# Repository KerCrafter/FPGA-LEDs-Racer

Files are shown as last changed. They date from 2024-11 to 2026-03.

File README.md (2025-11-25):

# LEDs Racer

## Description

A fun little game, 4 players (Red, Blue, Green, Yellow) around a table, each with an arcade button, must challenge each other by pressing their button as fast as possible.

Pressing the button causes their led to progress to the center circle. The first to reach the center wins.

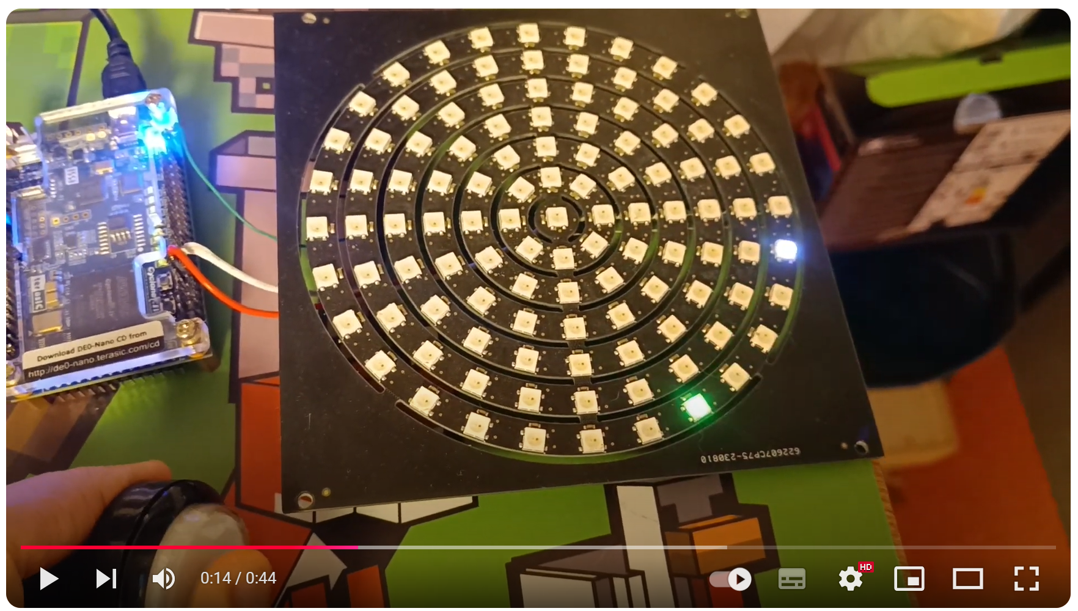
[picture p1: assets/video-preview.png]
Video Preview (https://youtu.be/GDuj1pzoBWQ)


## Platforms

### FPGAs

- DE0 Nano

### Tiny Tapeout Chips 

| Chip Name | Build | Status |
|--|--|--|
| [**TTSKY25b**](https://tinytapeout.com/chips/ttsky25b/tt_um_kercrafter_leds_racer) |    | Submitted (production in progress) |
| [**TTGFp02**](https://app.tinytapeout.com/projects/3455) |    | Submitted (production in progress) |
| **TTIHP26a** | Upcoming project | Not Submitted |

## Hardware

I'm putting here the material I used for the project, but of course if it's compatible this list can be adapted.

- 4 x **Arcade buttons** (https://www.amazon.fr/EG-STARTS-Nouveau-Boutons-poussoirs-lumineux/dp/B01MSNXLN0/)
- 1 x **LEDs Circles (with WS2812B Leds)** (https://www.amazon.fr/Treedix-anneaux-WS2812B-adressable-Raspberry/dp/B0CD3DYJRK/)
- 1 x **FPGA DE0 Nano** (https://www.mouser.fr/ProductDetail/Terasic-Technologies/P0082?qs=ePbE9GiMmvUo6nLfdjJv4g%3D%3D)

## Software IDE

I'm putting here the software I use for development to date. It's possible that these technical considerations may change depending on the target material.

- Quartus Prime Lite
- Questa Sim

## Install

Go to this [install guide](./docs/install.md)

## Run Unit Test Benches (With VUnit)

Require **Docker Client** installed and just run :

`./run_tests.sh`

## Actual State
**549** Logic Element (LE) - **232** Registers

I concentrated mainly on implementing the WS2812B LED driver. With the help of the testbench tool, I implemented tests as I went along in order to discover the communication algorithm with the WS2812B LED serial line.

the project works correctly End to End with DE0 Nano device.

### Todo options

- Music
- Random traps
- [Electronic Experimentation] Reduce number of CLK edges required to debounce button, it could be interesting to test with a capacitor.

### Identified problems

- From Test Bench we identify a problem about the RED Player led seems move two positions direcly : it's described in [LEDs_racer_main_tb](./LEDs_racer_main_tb.vhd#L414) / [this doc](./docs/sim_counter_problem.md)

## Architecture (Top View Usage)

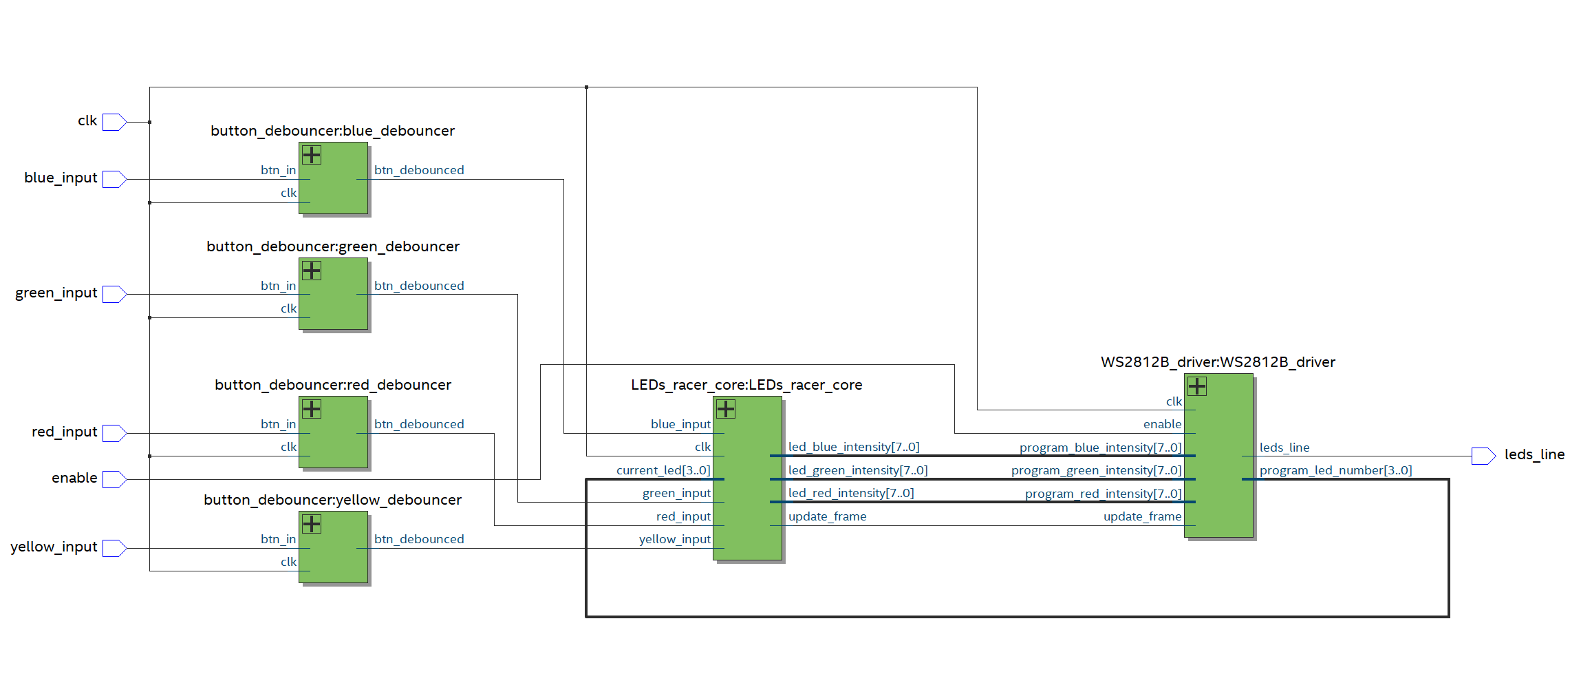
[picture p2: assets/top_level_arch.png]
Top View Architecture


|  pin input | input description  | output description |  pin output |
|  :--- |  :--- | ---: |  ---: |
|  **clk**  |  50 Mhz clock input signal  |  WS2812B transmission  |  **leds_line**  |
|  **red_input**  |  Player Red input (connected to Red button) or Grounded  | |  |
|  **green_input**  |  Player Green input (connected to Green button) or Grounded  | |  |
|  **blue_input**  |  Player Blue input (connected to Blue button) or Grounded  | |  |
|  **yellow_input**  |  Player Yellow input (connected to Yellow button) or Grounded  | |  |

### LEDs Racer Core Architecture

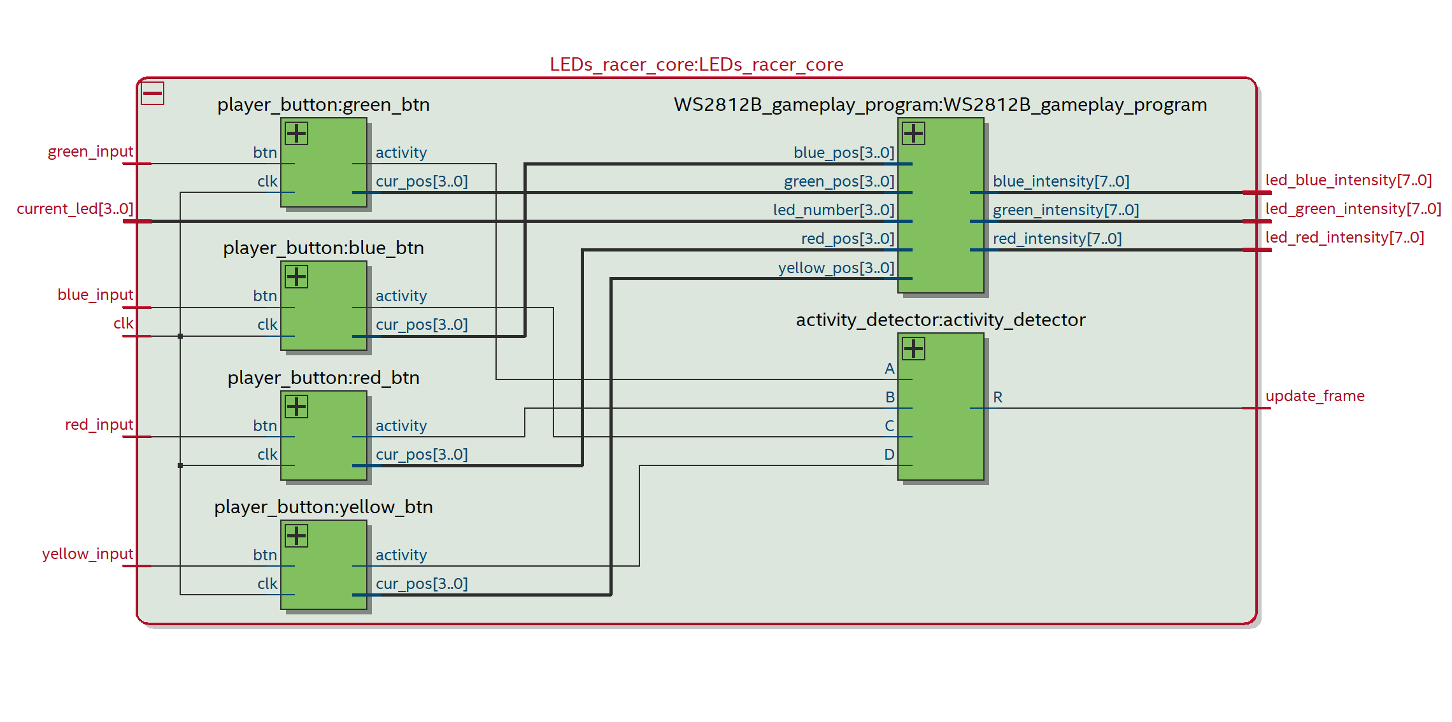
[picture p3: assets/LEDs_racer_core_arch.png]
LEDs Racer Core Architecture


### See more about sub-components

- [Button Debouncer](https://github.com/KerCrafter/button-debouncer)
- [Player Button](./docs/player_button.md)
- [Activity Detector](./docs/activity_detector.md)
- [WS2812B Driver](https://github.com/KerCrafter/WS2812B-driver)
- [WS2812B Gameplay Program](./docs/ws2812b_gameplay_program.md)

## Schematic

### Buttons

Should be connected to the FPGA inputs with a pull down resistor (note: not sure 1M is an ideal value)

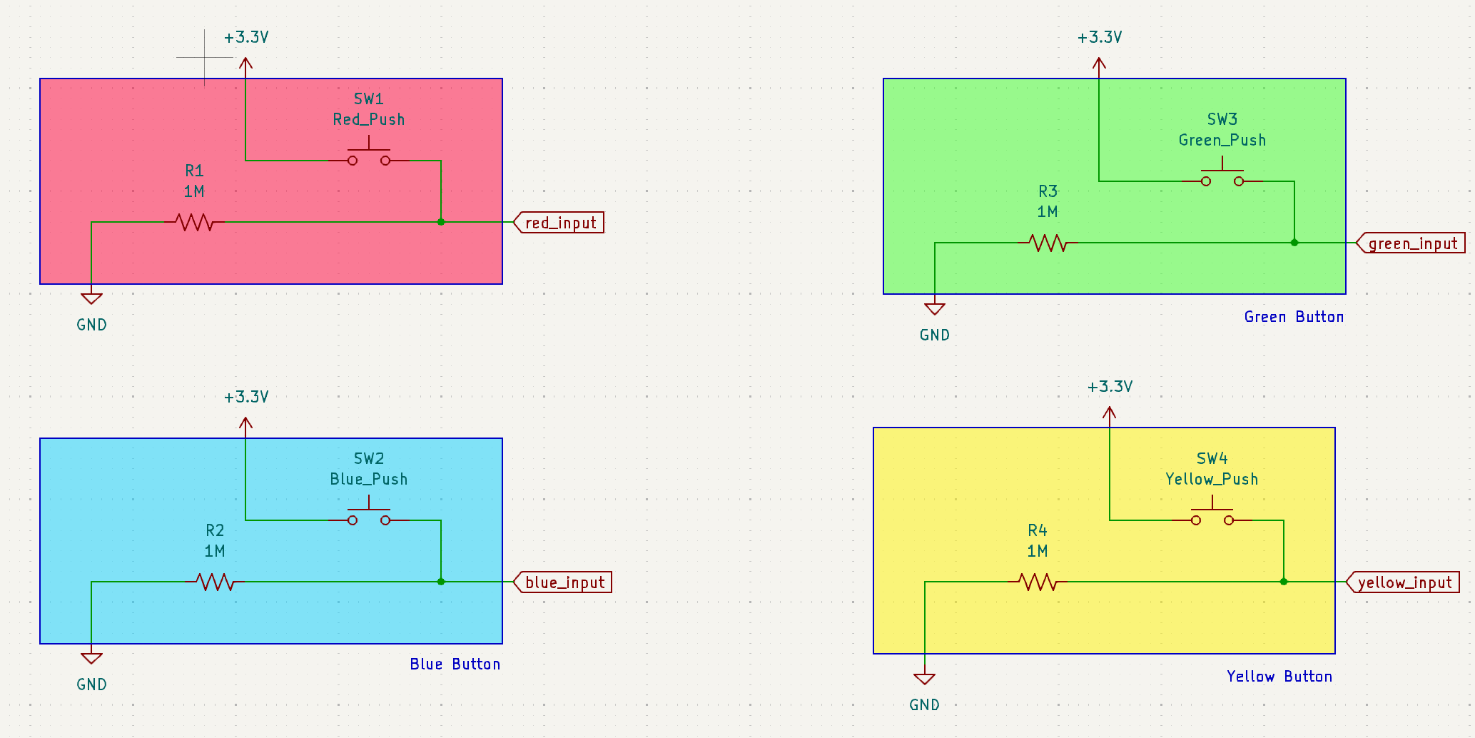
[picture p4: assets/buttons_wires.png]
Buttons Wires

[race_4_players.kicad_sch](./schematic/race_4_players/race_4_players.kicad_sch)

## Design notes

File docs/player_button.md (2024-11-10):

# Player Button

Manage the input for ONE player, typically Yellow player implement one instance of this

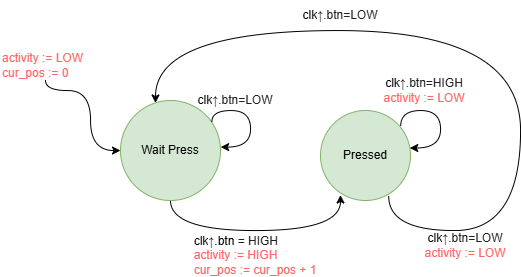
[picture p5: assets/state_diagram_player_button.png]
State Diagram of Player Button


## Responsabilities :

- Increments a counter at each press into the button
- Send a short impulsion just to inform that the displayed informations has changed

## RTL Architecture

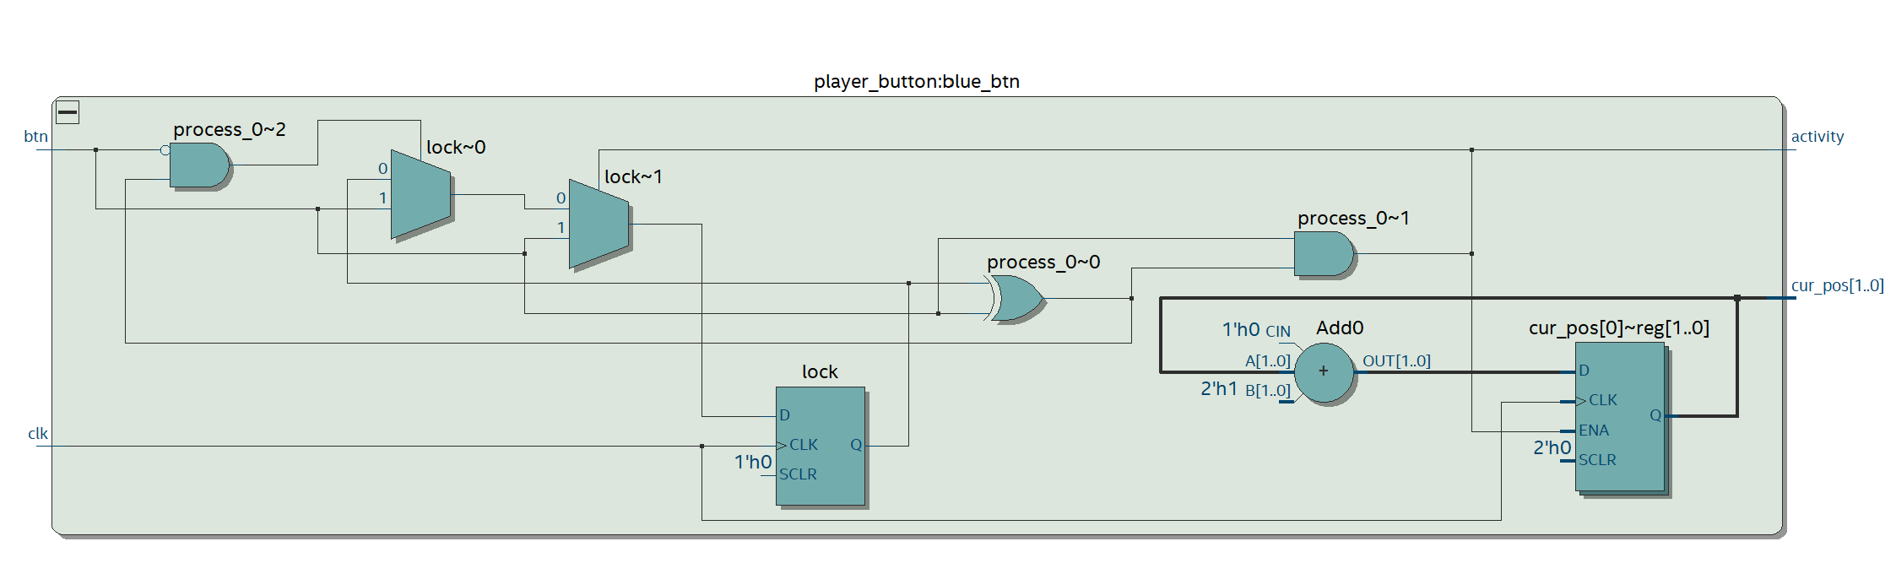
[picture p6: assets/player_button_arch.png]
Player Button Architecture


|  pin input | input description  | output description |  pin output |
|  :--- |  :--- | ---: |  ---: |
|  **clk**  |  50 Mhz clock input signal  |  Up to HIGH during one clk cycle when button is pressed  |  **activity**  |
|  **btn**  |  Connected to the button  | Actual position of the player | **cur_pos[1..0]** |

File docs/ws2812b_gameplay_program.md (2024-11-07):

# WS2812B Gameplay Program

Displaying logic per LEDs. designed to work with WS2812B Driver.

## Responsabilities :

- Receive players positions 
- Reveive position of current LED should be coded
- Send Green/Red/Blue light intensity for the WS2812B driver

## Displaying Rules

- White (Green: 5, Red: 5, Blue: 5) when 2+ players are in the LED.
- Black (OR light off => Green: 0, Red: 0, Blue: 0) when no players are actually in the LED.
- Green (Green 10, Red: 0, Blue: 0) when only Green player is in the LED.
- Red (Green 0, Red: 10, Blue: 0) when only Red player is in the LED.
- Blue (Green 0, Red: 0, Blue: 10) when only Blue player is in the LED.
- Yellow (Green 5, Red: 5, Blue: 0) when only Yellow player is in the LED.

## RTL Architecture 

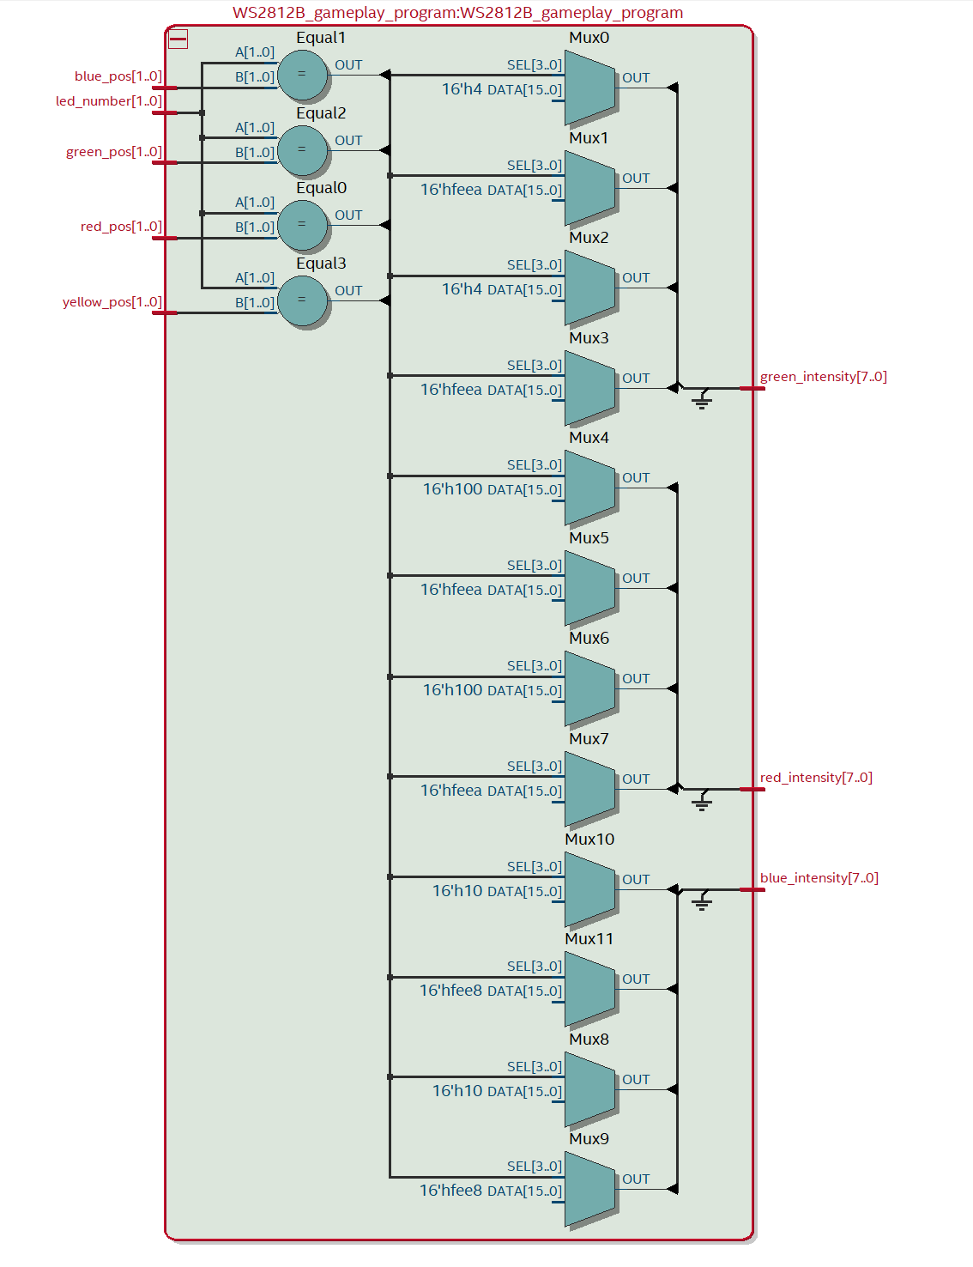
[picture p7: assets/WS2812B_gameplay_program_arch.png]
WS2812B Gameplay Program Architecture


|  pin input | input description  | output description |  pin output |
|  :--- |  :--- | ---: |  ---: |
|  **led_number[1..0]**  |  Position of the current coded led  |  Green light intensity emited (0 - 255) |  **green_intensity[7..0]**  |
|  **red_pos[1..0]**  |  Position of Red player  | Red light intensity emited (0 - 255) | **red_intensity[7..0]** |
|  **green_pos[1..0]**  |  Position of Green player  | Blue light intensity emited (0 - 255) | **blue_intensity[7..0]** |
|  **blue_pos[1..0]**  |  Position of Blue player  | | |
|  **yellow_pos[1..0]**  |  Position of Yellow player  | | |

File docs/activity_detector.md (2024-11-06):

# Activity Detector

Manage the 4 buttons activity signals (typically a simple 4 input OR)

## Responsabilities :

- Merge the buttons activity signals

## RTL Architecture

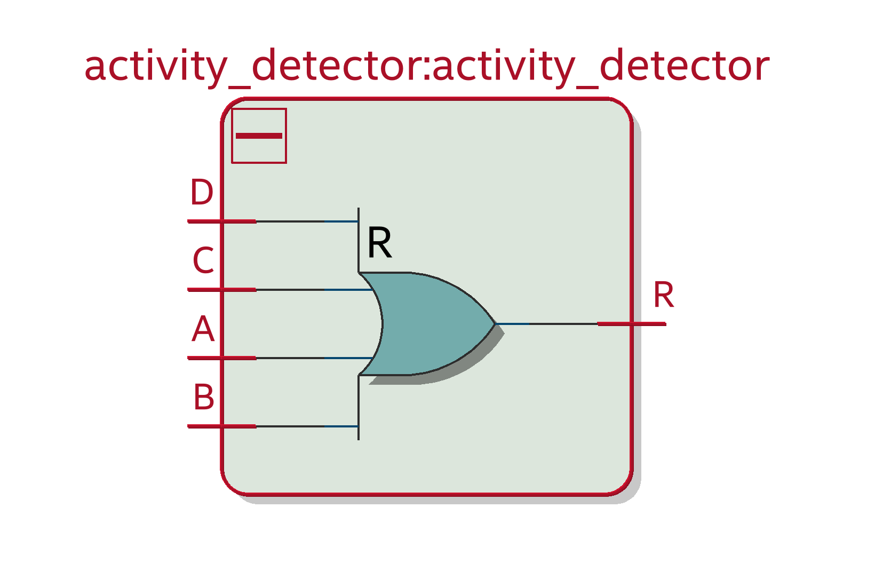
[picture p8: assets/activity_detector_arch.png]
Activity Detector Architecture


|  pin input | input description  | output description |  pin output |
|  :--- |  :--- | ---: |  ---: |
|  **A**  |  Player Activity signal  |  Merge result  |  **R**  |
|  **B**  |  Player Activity signal  |  |  |
|  **C**  |  Player Activity signal  |  |  |
|  **D**  |  Player Activity signal  |  |  |

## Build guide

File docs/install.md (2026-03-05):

# Install

## Clone this repository and submodules

run `git clone --recurse-submodules https://github.com/KerCrafter/FPGA-LEDs-Racer.git`

## Create Quartus Project (Automatic Mode)

**Require docker installed**

### Prepare Quartus Docker Image

Download Quartus Lite **.run** file from [Altera Website](https://www.altera.com/downloads/fpga-development-tools/quartus-prime-lite-edition-design-software-version-25-1-linux), place this file into `quartus-cli/` folder.

and run `cd quartus-cli/ && ./build.sh && cd -`

### Create the quartus project

just run script `./create_quartus_project.sh`

or, to compile run `./flow_compile.sh`

## Create Quartus Project (Manual Mode)

From this project repository we ignore Quartus Project files. we includes only sources files.

You need open Quartus IDE and go to `File > New Project Wizard...` 

### Directory, Name, Top-Level Entity

**Directory:** select the folder where you have cloned the project
**Name:** name the project as you wish, personally I put `LEDs-racer`
**Top-Level Entity:** put `DE0_NANO_LEDs_racer_main`

### Project Type

select `Empty project`

### Add Files

click to the `...` button, and add each `.vhd` files, except `*_tb.vhd` dedicated to the simulation.

### Family, Device & Board Settings

**Family:** Cyclone IV E

In `Available devices` search the model `EP4CE22F17C6` (as a precaution, check the reference on your DE0 Nano's chip)

And press on Finish, congratulations the project is ready

## Mapping inputs/outputs

From Pin Planner tool you can specify the matching pins for DE0_nano

| Node Name | Direction | Location |
| - | - | - |
| clk | input | PIN_R8 |
| green_input | input | PIN_T13 |
| red_input | input | PIN_T15 |
| blue_input | input | PIN_T12 |
| yellow_input | input | PIN_T14 |
| leds_line | output | PIN_D3 |

## Setup simulation

I currently use Questa to simulate component execution. You need to configure the free license correctly, otherwise the simulation won't run.

Once your account has been created, your PC registered, a license requested and collected by email from intel.
- [Intel® FPGA Licensing Support Center](https://www.intel.com/content/www/us/en/support/programmable/licensing/support-center.html)
- [Setup Quartus License Windows](https://www.terasic.com.tw/wiki/Setup_Quartus_License_Windows)

### Configure a simulation (actually not included in Automatic Mode)

In Quartus, go to `Assignments > Settings...`

Go to `EDA Tool Settings > Simulation` tab

**Tool name:** must be Questa Intel FPGA
in NativeLink settings section, press in `Test Benches...` button

`New...` button to add a new testbench configuration

**Test bench name** match with the name of the testbench. for instance `LEDs_racer_core_tb`

**Top level module in test bench** match with the name of the top level module typicaly same **Test bench name**

Need include the file for this test bench, for instance `LEDs_racer_core_tb.vhd`

### Run simulation

In root of Quartus, go to `Tools > Run Simulation Tool > RTL Simulation` should run Questa for your setup testbench.

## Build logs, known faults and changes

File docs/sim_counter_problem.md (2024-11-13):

# Simulation Problem

In my Quartus environment, Using Questa Sim. A player counter seems Move to 2 positions instead of expected 1 postion.

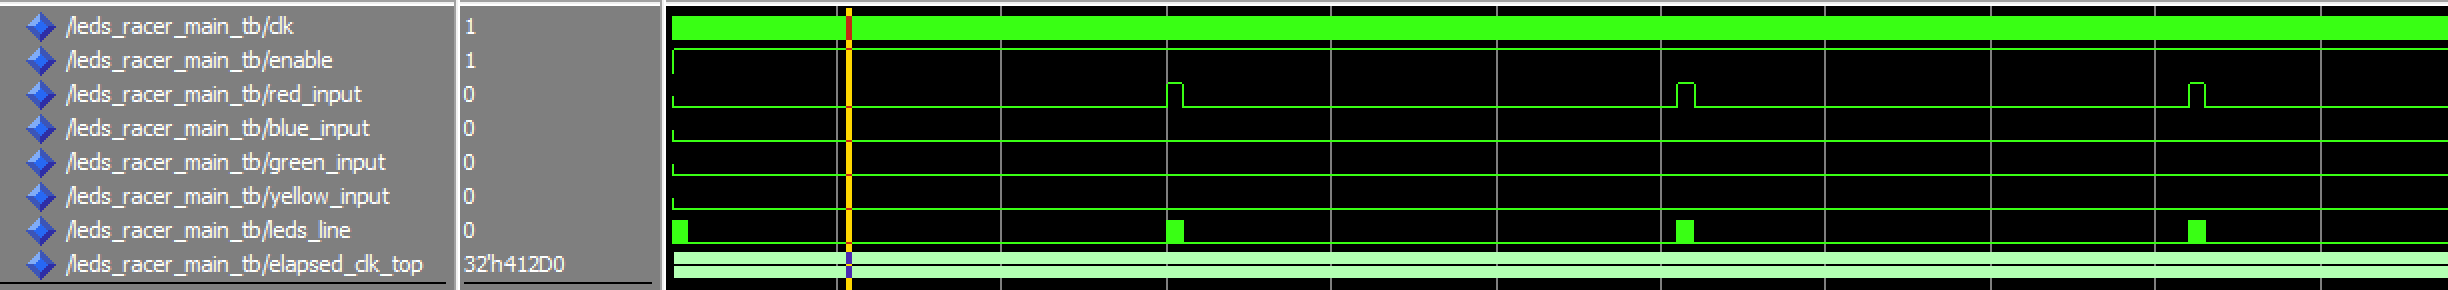
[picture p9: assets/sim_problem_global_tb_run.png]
Global Test Flow


Execution of [LEDs_racer_main_simu_problem_tb.vhd](../LEDs_racer_main_simu_problem_tb.vhd)

I've isolate the problem in a specific Test Bench. It seems appear when I try to work with 15+ LEDs.

**note :** [LEDs_racer_main_tb.vhd](../LEDs_racer_main_tb.vhd) (with 14 LEDs) works fine.

## Test Flow

Starting, `enable` pin is LOW state. Then we assume Red / Green / Blue / Yellow players are at position `0`.

When I change `enable` (not correcly named, may be `start` pin) to HIGH : First data frame is sent to LEDs via output `leds_line`
Via the Test Bench we assert signal sent is correct, then :

 - First LED is White (Players Red + Green + Blue + Yellow are here).
 - Next LEDs are Black (Lights off)

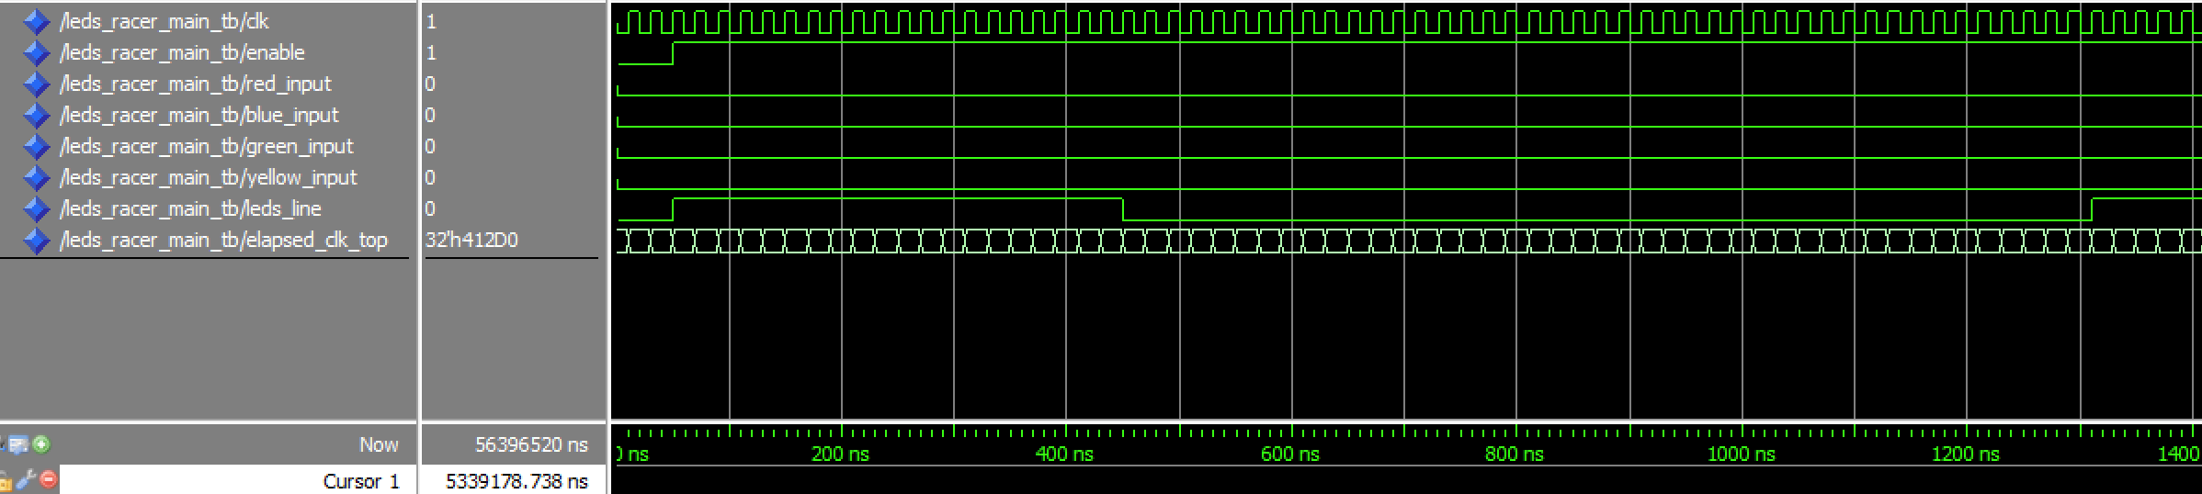
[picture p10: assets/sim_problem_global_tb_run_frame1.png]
Global Test Flow Frame 1


When Red Player press in his button, `red_input` is HIGH : Second data frame is sent

 - First LED is White (Players Green + Blue + Yellow are here)
 - Second LED is Red (Only Red player is here)
 - Next LEDs are Black (Lights off)

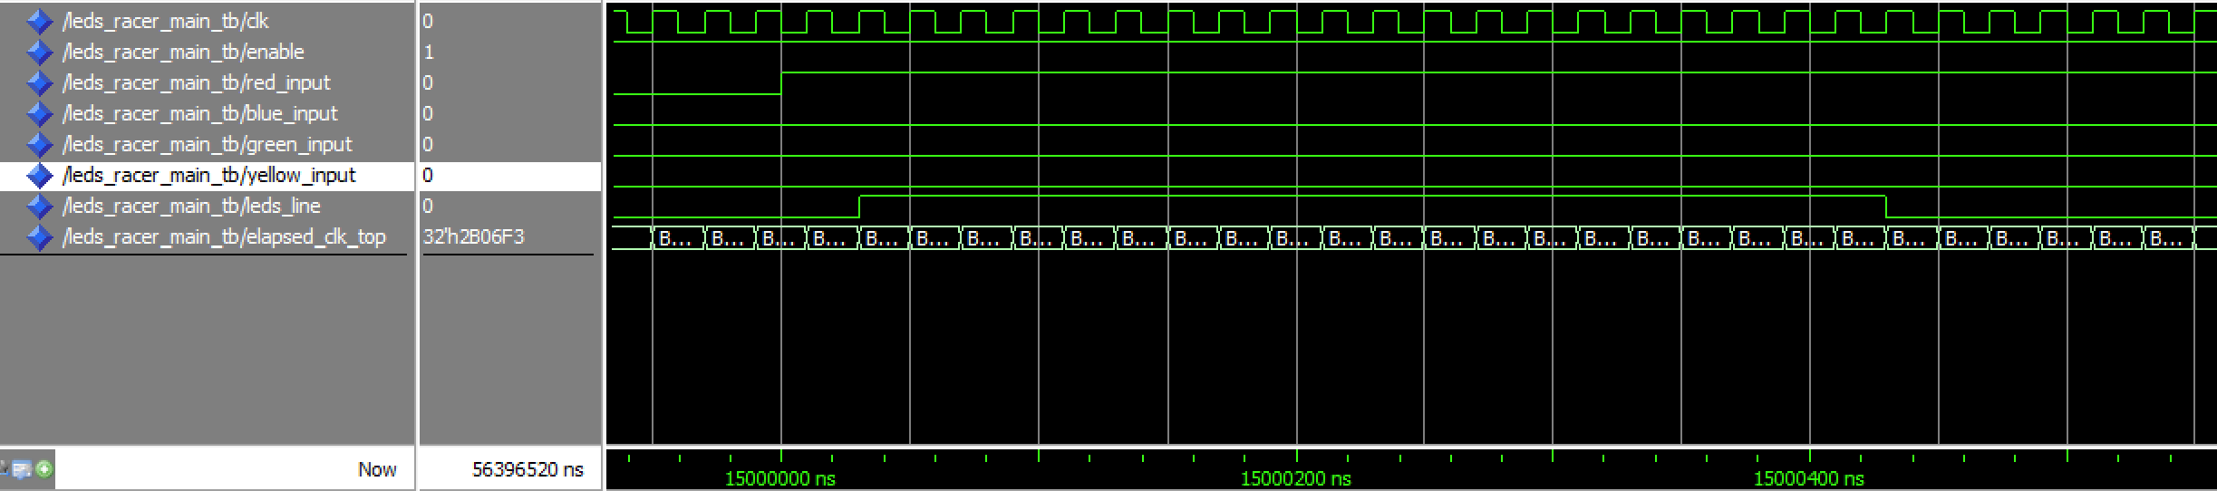
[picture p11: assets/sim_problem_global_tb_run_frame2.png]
Global Test Flow Frame 2


When Red Player press in his button second times, `red_input` is HIGH : 3rd data frame is sent

 - First LED is White (Players Green + Blue + Yellow are here)
 - Second LED is Black (no player is here)
 - 3rd LED is Black (no player is here)
 - 4th LED is Red (Only Red player is here)
 - Next LEDs are Black (Lights off)

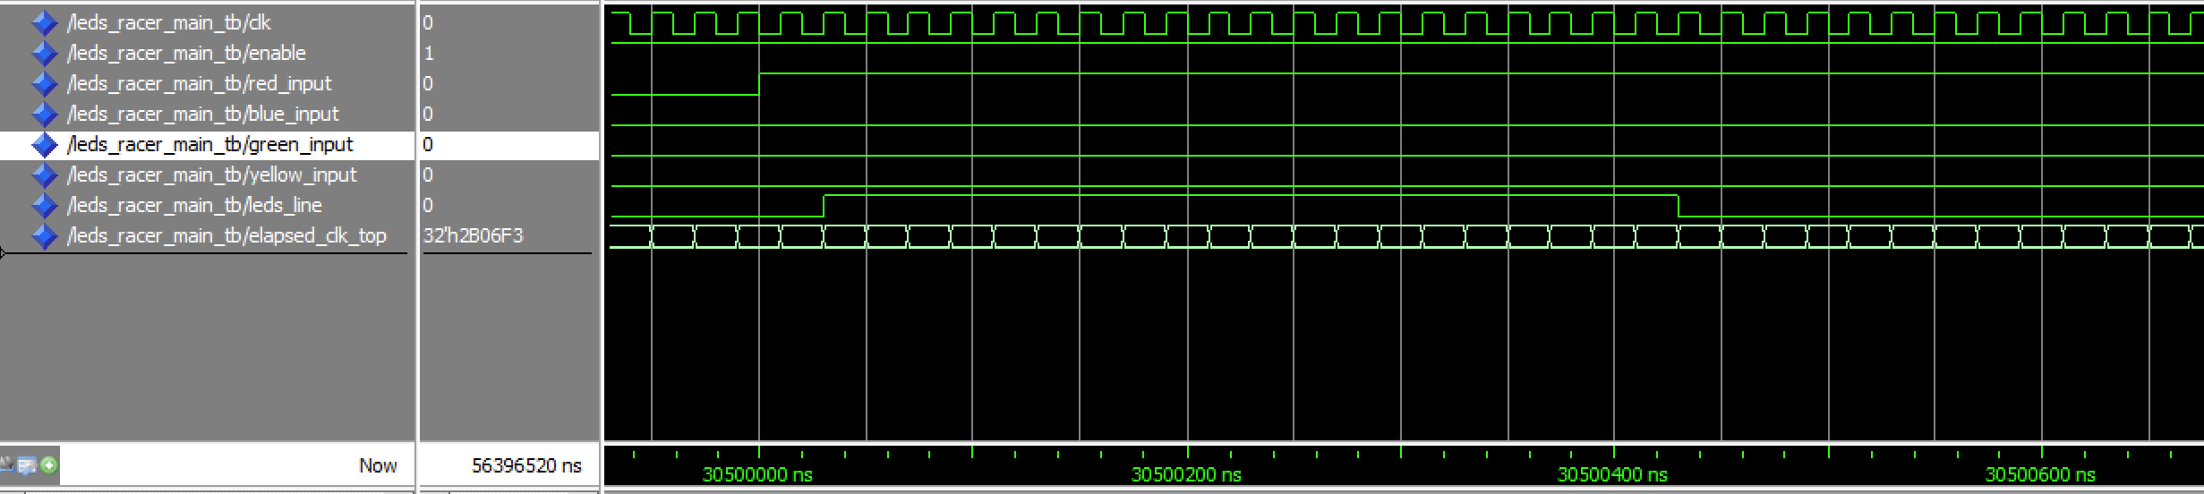
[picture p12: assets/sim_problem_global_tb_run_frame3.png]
Global Test Flow Frame 3


To manange the position of Players, the Entity [Player Button](../player_button.vhd) implement a counter. The same tests with `3-bit` counter works fine.

- I use `numeric std` to use `integer` for `+1` operation. it implement a `Binary Adder`. other possible implementation may be implement a `Binary Counter` with nested FF.

- Independently, I've add a Test Bench to test only the [Player Button](../player_button.vhd) in [Player Button Test Bench](../player_button_tb.vhd), this test display a very good behaviour for this component.

- WS2812B Driver seems works correcly, I've test with 9 trigger of frames with 5000 LEDs... [WS2812B Driver TestBench](../WS2812B_driver_tb.vhd)

State Diagram of Player Button

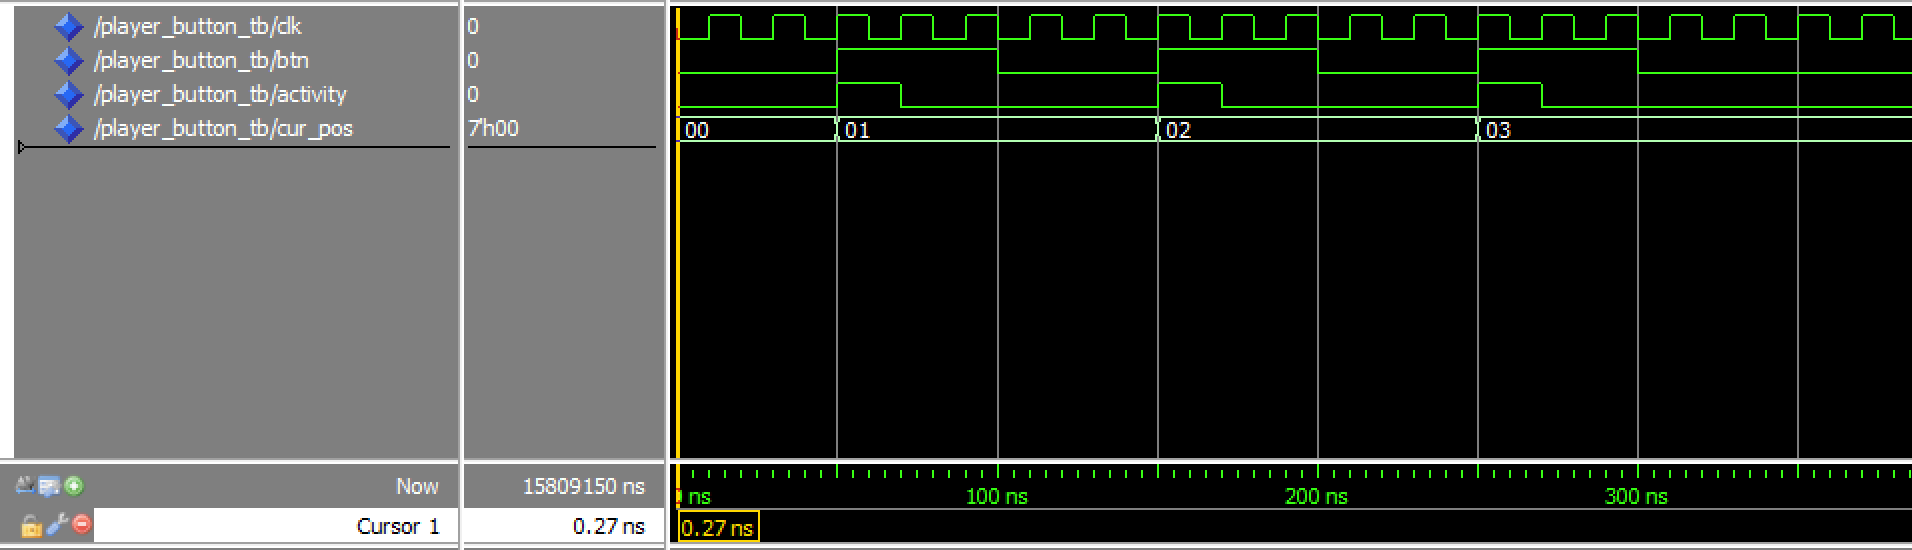
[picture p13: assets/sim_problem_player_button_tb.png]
Player Button Test Bench Result

Player Button Test Bench Result

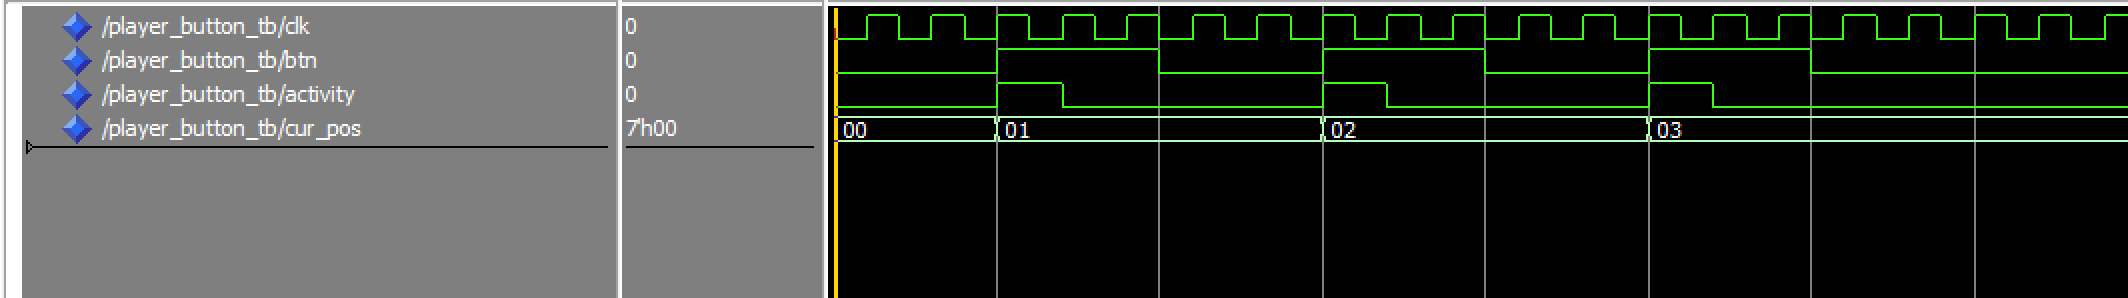
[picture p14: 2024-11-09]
assets/spot_problem_player_button_activity_output_fixed.png

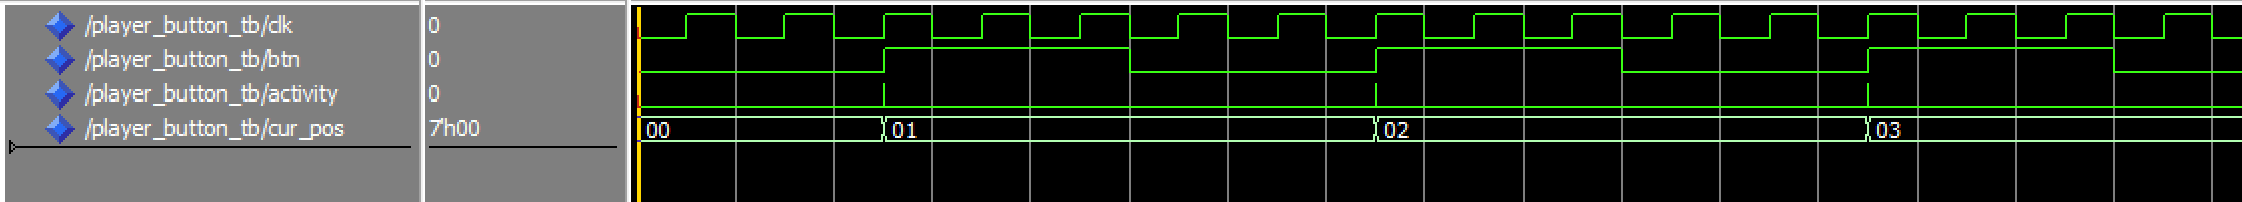
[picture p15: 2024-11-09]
assets/spot_problem_player_button_activity_output.png

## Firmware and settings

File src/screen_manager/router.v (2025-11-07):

`default_nettype none

module router #(
    parameter MAX_POS = 109
)(
    input wire [6:0] green_cur_pos,
    input wire [6:0] red_cur_pos,
    input wire [6:0] blue_cur_pos,
    input wire [6:0] yellow_cur_pos,
    input  wire is_in_menu,
    output reg [1:0] current_screen
);

    wire game_in_progress_screen;
    wire game_finished_screen;

    is_game_finished #(
        .MAX_POS(MAX_POS)
    ) is_game_finished_inst (
        .is_in_menu(is_in_menu),
        .green_cur_pos(green_cur_pos),
        .red_cur_pos(red_cur_pos),
        .blue_cur_pos(blue_cur_pos),
        .yellow_cur_pos(yellow_cur_pos),
        .result(game_finished_screen)
    );

    is_game_started #(
        .MAX_POS(MAX_POS)
    ) is_game_started_inst (
        .is_in_menu(is_in_menu),
        .green_cur_pos(green_cur_pos),
        .red_cur_pos(red_cur_pos),
        .blue_cur_pos(blue_cur_pos),
        .yellow_cur_pos(yellow_cur_pos),
        .result(game_in_progress_screen)
    );

    always @(*) begin
        if (is_in_menu)
            current_screen = 2'b00;
        else if (game_in_progress_screen)
            current_screen = 2'b01;
        else if (game_finished_screen)
            current_screen = 2'b10;
        else
            current_screen = 2'b11;
    end

endmodule

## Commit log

2024-11-03 stage register optimization (54 -> 56 LE / 25 -> 24 Reg)
2024-11-04 manage red_input instead of red_pos (button red connected in)
2024-11-04 rename WS2812B driver to LEDs racer main : for the moment git pushproblem detected at synthesis (only Simulation works)
2024-11-04 synthetizable code manage the red button
2024-11-05 extract buttons as separate components + optimize registers
2024-11-05 remove unused old user buttons entity
2024-11-05 prepare test bench for button debouncer (goal avoid hardware bouncing signal when button is pressed)
2024-11-06 prepare btn stimulations to simulate interfering signal on press button
2024-11-06 button debouncer : build empty UUT and link to test bench
2024-11-06 separate WS2812B driver in entity
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2024-11-07 kicad schematic file
    [race_4_players.kicad_sch]
2024-11-07 kicad link in Readme
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2024-11-07 wip btn debouncer, work with a button with a stable press
2024-11-07 just try to connect button de bouncer in Green button. but I see strange behaviour. I suspect it about the problem to not waiting 50us above to validate query
2024-11-08 works fine with other debounce clk times (3 -> 65537) and manage others LEDs (4 -> 108) warning test bench KO for normal reason
2024-11-09 move WS2812B driver entity in separate file
2024-11-09 add test bench for player button entity, it spot a strange behaviour, but not solve the main problem
2024-11-09 problem root identified, seems the adder for player button. it can be interested to implement a counter with cascade toggle FF
2024-11-10 state diagram of player button component
2024-11-10 implement generic for player button to try isolate problem about counter
2024-11-10 implement generic for ws2812b driver to try isolate problem about counter
2024-11-13 simulation specific on WS2812B Driver correct
2024-11-13 prepare for extraction of WS2812B driver to specific repository
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2024-11-14 extract LEDs_racer_core in specific component entity with test bench
2024-11-14 add button debouncer as submodule
2024-11-14 extract button debouncer as submodule
2024-11-17 declare generic value for button debouncer
2024-11-17 move implementation of button debouncer as an adapter dependency of LEDs_racer_main instead of LEDs_racer_core
2024-11-17 apply the new generic in test benches of LEDs racer main
2024-11-17 implement button debouncer for red input
2024-11-18 add test for 4rd Red Led
2024-11-18 add test for 2nd Blue LED
2024-11-18 add test for 3rd Blue LED
2024-11-18 add test for 4th Blue LED
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2024-11-19 doc include button debouncer in sub components
2024-11-19 leds racer core architecture documentation
2024-11-19 When GREEN got to last (LED 4) should display all leds in green : test just for 1st led
2024-11-19 all LEDs are green
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2024-11-24 adapt with new interface of WS2812B Driver to manage tri-state buffer with gameplay program entity
2024-11-26 adapt tests to new WS2812B driver way (enable / trigger works identicaly)
2024-11-26 by default works with 109 LEDs
2024-11-26 program for 109 LEDS & green win at the last LED
2024-11-27 refactor with procedure to set GRB LED intensity
2024-11-28 apply procedure assert_GRB for each leds
2024-11-29 work but little latency detected during switch of screen
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2024-12-01 add testbench to try explain why all players start in 2nd led, but this tes bensch not explain. It seems specific to DE0 Nano
2024-12-01 explain 2nd led starting in readme
2024-12-05 refactoring in Leds racer core testbench
2024-12-05 just update WS2812B & button debouncer testbenches
2024-12-06 set ff=unix to LEDs_racer_main_tb.vhd
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2025-04-16 just not increment counter when current screen isn't the 'game started'
2025-04-18 add on_menu signal input in player_button to allow capacity to declare user ready to play in the game
2025-04-19 wire player_buttons on menu with screen manager
2025-04-19 wire ready to plays with screen manager
2025-04-19 wire is_in_menu with is_game_started & is_game_finished
2025-04-20 introduce wire (2bit) to transmit current screen information
2025-04-20 refactor player button using new concpet of current_screen
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2025-04-21 wire current_screen info to screens entity
2025-04-22 remove wires 'ready to play' in router
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2025-04-24 manage correclty vunit LEDs racer code for green wins + blue wins
2025-07-19 fix bug buffer, player button
2025-07-19 optimize to not use clk into player button
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2025-08-03 update schematic (include de0 nano mini header)
    [de0_nano_mini.kicad_sch, race_4_players.kicad_sch]
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2025-08-14 replace enable input signal & update WS2812B driver
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2025-09-15 menu diplay led 1 red when is press his button
2025-09-15 menu diplay led 2 red when is ready to play
2025-09-15 menu diplay led 3 red when is ready to play
2025-09-15 menu diplay led 4 red when is ready to play
2025-09-15 menu diplay led 5-6 red when is ready to play
2025-09-18 When countdown is 7 led 0 should be white
2025-09-18 When countdown is 7 led 21 should be white
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2025-09-26 menu timer integrated to menu manager (problem, seems long from TU)
2025-09-27 reduce clk count for menu timer in test bench
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2025-09-28 check trigger update frame behaviour when player press button
2025-09-28 refacto move update frame check procedure to assertions package
2025-09-28 add simulation to check update frame behaviour when green player press button
2025-09-28 add simulation to check update frame behaviour when blue player press button
2025-09-28 add simulation to check update frame behaviour when yellow player press button
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2025-09-30 trigger good update frame when red player press his button
2025-09-30 trigger good update frame when blue or green player press his button
2025-09-30 trigger good update frame when yellow player press his button
2025-10-02 gameplay program remove tri-state (just light off leds)
2025-10-02 finished logic screen remove tri-state (just light off leds)
2025-10-02 menu logic screen remove tri-state (just light off leds)
2025-10-03 after 1 sec when 2 players are ready should trigger update frame (todo optimize this)
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
